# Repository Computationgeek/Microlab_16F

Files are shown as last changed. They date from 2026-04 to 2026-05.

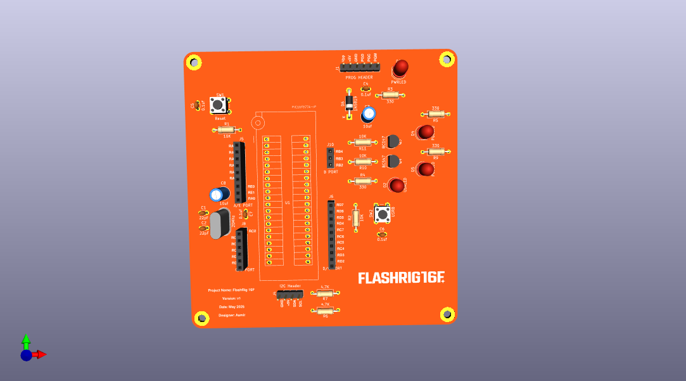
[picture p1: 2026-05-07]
FLASHRIG16F/images/ML16FPCB.png

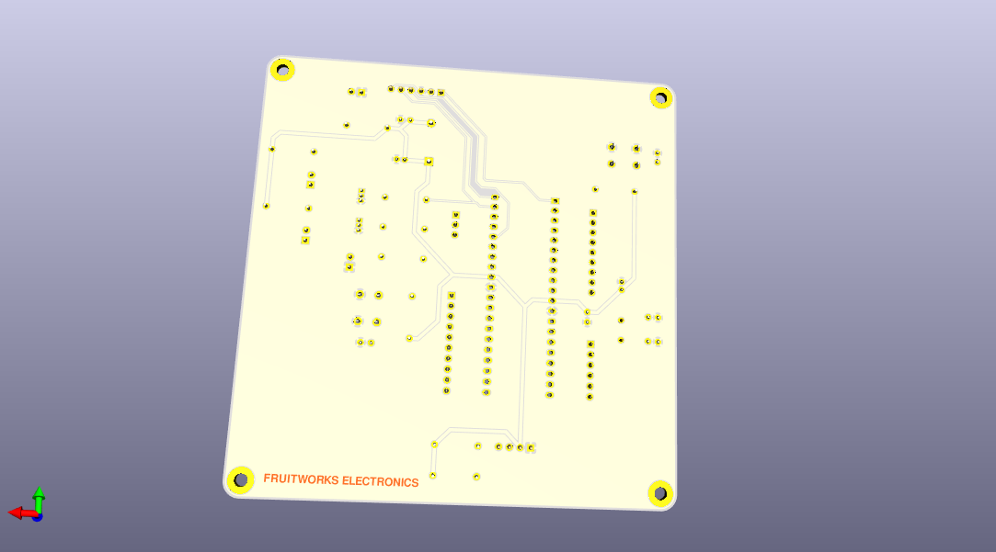
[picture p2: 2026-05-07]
FLASHRIG16F/images/ML16FPCBbcy.png

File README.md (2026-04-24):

# MicroLab 16F - PIC16F877A Development Board  
A hand-soldered PIC16F877A development board built entirely on perfboard. This project was born from a desire to gain a deep understanding of embedded systems hardware by building everything from scratch - no pre-made modules, no shortcuts.

hkio

## Vision & Motivation

In 2026, most developers rely on modern MCUs like ESP32 and STM32. But there's something special about PIC microcontrollers - they force you to understand registers, bit manipulation, and hardware at a fundamental level: no HAL abstraction, no hand-holding.

I built MicroLab 16F because:
- **Learning by doing** - Soldering each connection taught me more than any tutorial
- **Legacy matters** - PIC16F877A is still widely used in education and industry
- **Maker ethos** - If you can't build it yourself, you don't truly understand it
- **Fun over perfection** - This isn't a product, it's a learning journey

## Features

### Hardware
- **PIC16F877A** microcontroller (40-pin DIP)
- **20MHz HS crystal** oscillator with 22pF load capacitors
- **Mini breadboard** integrated prototyping area
- **10kΩ potentiometer** connected to RA0 (ADC input)
- **Active buzzer** driven by BC547 NPN transistor on RD1
- **User-addressable LED** on RB0
- **Two tactile buttons** - User button (configurable) and Reset button (MCLR)
- **USB-C power input** with 5V regulation
- **PICkit3 programming header** (ICSP interface)
- **Labeled pin headers** for all GPIO ports (PORTA, PORTB, PORTC, PORTD, PORTE)

### Power System
- USB-C input with 5V output
- Dedicated power LED indicator
- Decoupling capacitors for stable operation
- External power compatible (PICkit3 or USB-C)

## Detailed Specifications

PIC16F877A_Pinout_600x600

| Parameter | Value |
|---|---|
| **Microcontroller** | PIC16F877A (Microchip) |
| **Architecture** | 8-bit RISC |
| **Program Memory** | 14.3 KB (8192 words) Flash |
| **RAM** | 368 bytes |
| **EEPROM** | 256 bytes |
| **Clock Frequency** | 20 MHz (HS Crystal) |
| **I/O Pins** | 33 |
| **ADC Channels** | 8 (10-bit resolution) |
| **Timers** | 3 (Timer0/1/2) |
| **PWM Channels** | 2 (CCP modules) |
| **Serial Interfaces** | USART, I²C, SPI |
| **Operating Voltage** | 5V DC |
| **Power Source** | USB-C (5V) |
| **Programming Interface** | ICSP (In-Circuit Serial Programming) |
| **Programmer** | PICkit3

## Components Used

### Main Components
| Component | Specification | Quantity | Purpose |
|---|---|---|---|
| PIC16F877A-I/P | 40-pin DIP | 1 | Main microcontroller |
| Crystal Oscillator | 20 MHz HC-49S | 1 | Clock source |
| Ceramic Capacitor | 22pF | 2 | Crystal load capacitors |
| Ceramic Capacitor | 100nF | 5+ | Decoupling/bypass |
| Electrolytic Capacitor | 10µF 16V | 2 | Power filtering |
| BC547 NPN Transistor | TO-92 | 1 | Buzzer driver |
| Active Buzzer | 5V | 1 | Audio output |
| LED (5mm) | Red/Green | 3 | Power, User, Status indicators |
| Resistor | 10kΩ | 5+ | Pull-ups, current limiting |
| Resistor | 330Ω | 3 | LED current limiting |
| Resistor | 1kΩ | 1 | Base resistor for BC547 |
| Potentiometer | 10kΩ linear | 1 | Analog input (RA0) |
| Tactile Switch | 6×6mm | 2 | User button, Reset button |
| Mini Breadboard | 170 points | 1 | Prototyping area |
| USB-C Connector | Breakout module | 1 | Power input |
| Pin Headers | 2.54mm pitch | Multiple | GPIO breakout |
| Perfboard | Single-sided | 1 | PCB substrate |
| IC Socket | 40-pin DIP | 1 | PIC mounting (optional) |

## Software & Tools

### Development Environment
- **IDE:** MPLAB X IDE v6.20 (Last version with PICkit3 support)
- **Compiler:** MPLAB XC8 v2.46 (Free edition)
- **Programmer:** PICkit3 In-Circuit Debugger/Programmer
- **OS:** Tested on Linux Mint 21.3 & Windows 10/11

### Programming Setup
```bash
# Linux users: Add udev rules for PICkit3
sudo nano /etc/udev/rules.d/26-microchip.rules

# Add this line:
SUBSYSTEM=="usb", ATTR{idVendor}=="04d8", ATTR{idProduct}=="900a", MODE="0666", GROUP="plugdev"

# Reload rules
sudo udevadm control --reload-rules
sudo udevadm trigger
```

### Configuration Bits (Standard Setup)
```c
#pragma config FOSC = HS        // High-Speed crystal oscillator
#pragma config WDTE = OFF       // Watchdog Timer disabled
#pragma config PWRTE = ON       // Power-up Timer enabled
#pragma config BOREN = ON       // Brown-out Reset enabled
#pragma config LVP = OFF        // Low-Voltage Programming disabled (CRITICAL for ICSP)
#pragma config CPD = OFF        // Data EEPROM Code Protection off
#pragma config WRT = OFF        // Flash Program Memory Write Enable off
#pragma config CP = OFF         // Flash Program Memory Code Protection off
```

## Getting Started

### 1. Power Up
Connect the USB-C cable to a 5V power source (laptop, power bank, or wall adapter).
The power LED should illuminate.

### 2. Connect Programmer
**PICkit3 Pinout (6-pin header):**
1 - MCLR  → PIC Pin 1 (MCLR/VPP)
2 - VDD   → PIC Pin 11, 32 (VDD) - For sensing only
3 - GND   → PIC Pin 12, 31 (VSS)
4 - PGD   → PIC Pin 40 (RB7/PGD)
5 - PGC   → PIC Pin 39 (RB6/PGC)
6 - NC    → Not connected

## Troubleshooting

### PICkit3 "Target VDD too low" Error
**Problem:** VDD measured as 4.75V instead of 5.0V during programming.

**Cause:** Board peripherals (buzzer, LEDs) draw more current than PICkit3 can supply (~30-50mA limit).

**Solution:** 
1. In MPLAB X: Project Properties → PICkit3 → Power → UNCHECK "Power target from tool"
2. Power board via USB-C only
3. PICkit3 is used for programming signals, not power

### Programming Fails at Address 0x0000
**Cause:** Incorrect config bits or MCLR circuit issue.

**Solution:**
- Ensure `LVP = OFF` in config bits
- Verify 10kΩ pull-up resistor on MCLR pin
- Try a slower programming speed in MPLAB X settings

See [docs/troubleshooting.md](docs/troubleshooting.md) for more.

## Learning Resources

### PIC16F877A Deep Dive
- [Microchip Official Datasheet](https://www.microchip.com/wwwproducts/en/PIC16F877A)
- [Gooligum Electronics PIC Tutorials](https://www.gooligum.com.au/PIC-tutorials) - Best assembly/register-level guide
- Microchip Application Notes: AN526 (Math routines), AN617 (Fixed-point math)

### Recommended Reading
- "PIC Microcontroller Project Book" by John Iovine
- "Programming PIC Microcontrollers with XC8" by Armstrong Subero
- Embedded.fm podcast episodes on PIC architecture

## Why PIC16F877A in 2026?

**Yes, it's 25+ years old. Here's why it still matters:**

1. **Educational Gold Standard** - Used in universities worldwide to teach embedded fundamentals
2. **Register-Level Programming** - No bloated HALs hiding what's actually happening
3. **Industry Workhorse** - Still found in industrial equipment, automotive, and legacy systems
4. **Simplicity** - 35 instructions vs 100+ in ARM Cortex
5. **Availability** - Cheap, plentiful, easy to source
6. **Hands-On Learning** - DIP package = breadboard/perfboard friendly

Modern isn't always better. Sometimes you need to go back to basics.

## License

MIT License - Build, modify, share freely. Just give credit.

## 🔗 Links

- **Build Story:** [Hackster.io Project](https://www.hackster.io/aamirayaaz5/building-a-pic16f877a-development-board-from-scratch-in-2026-7d29bc)
- **LinkedIn Post:** [LinkedIn Post about the board](https://www.linkedin.com/posts/aamir-ayaaz-b5549a220_embeddedsystems-electronicsengineering-hardwaredesign-activity-7425852984116404224-cy4W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)

## Acknowledgments

Built with:
- Lots of solder fumes
- Multiple debugging sessions
- A stubborn refusal to give up when VDD dropped to 4.75V
- Coffee

**Special thanks to the PIC community and all the forum posts from 2005-2015 that saved this project.**

---

*"If you can't build it yourself, you don't truly understand it."*

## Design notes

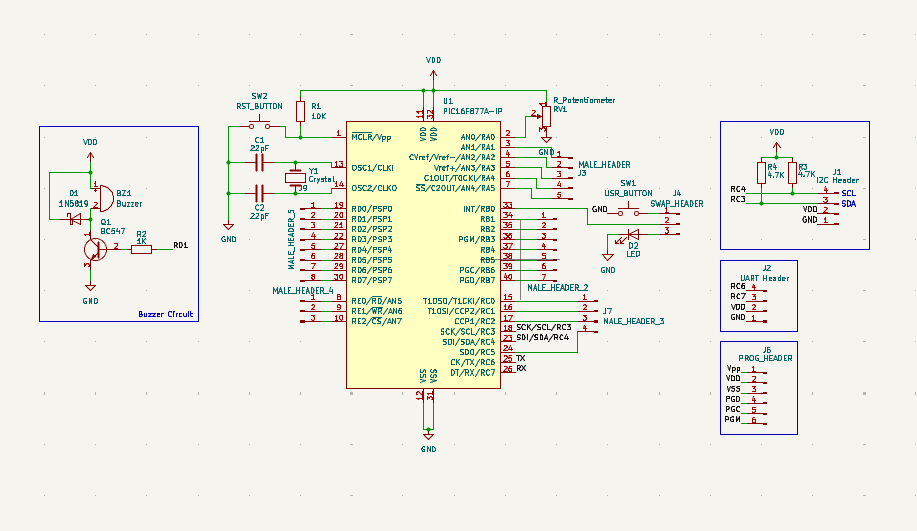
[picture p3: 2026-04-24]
Schematic/Schematic.png

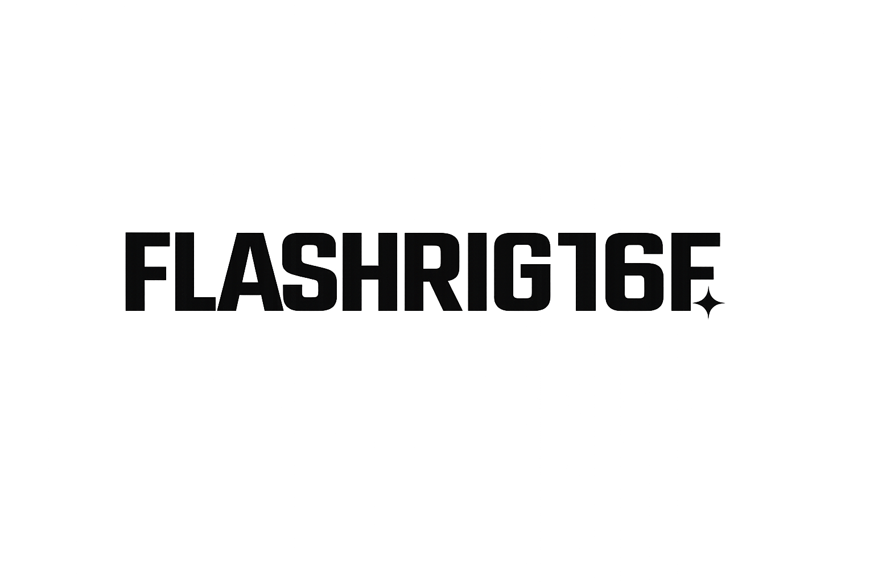
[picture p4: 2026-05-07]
FLASHRIG16F/images/3267ec91-bc9a-4d5c-b8c6-06fcff0d2900.png

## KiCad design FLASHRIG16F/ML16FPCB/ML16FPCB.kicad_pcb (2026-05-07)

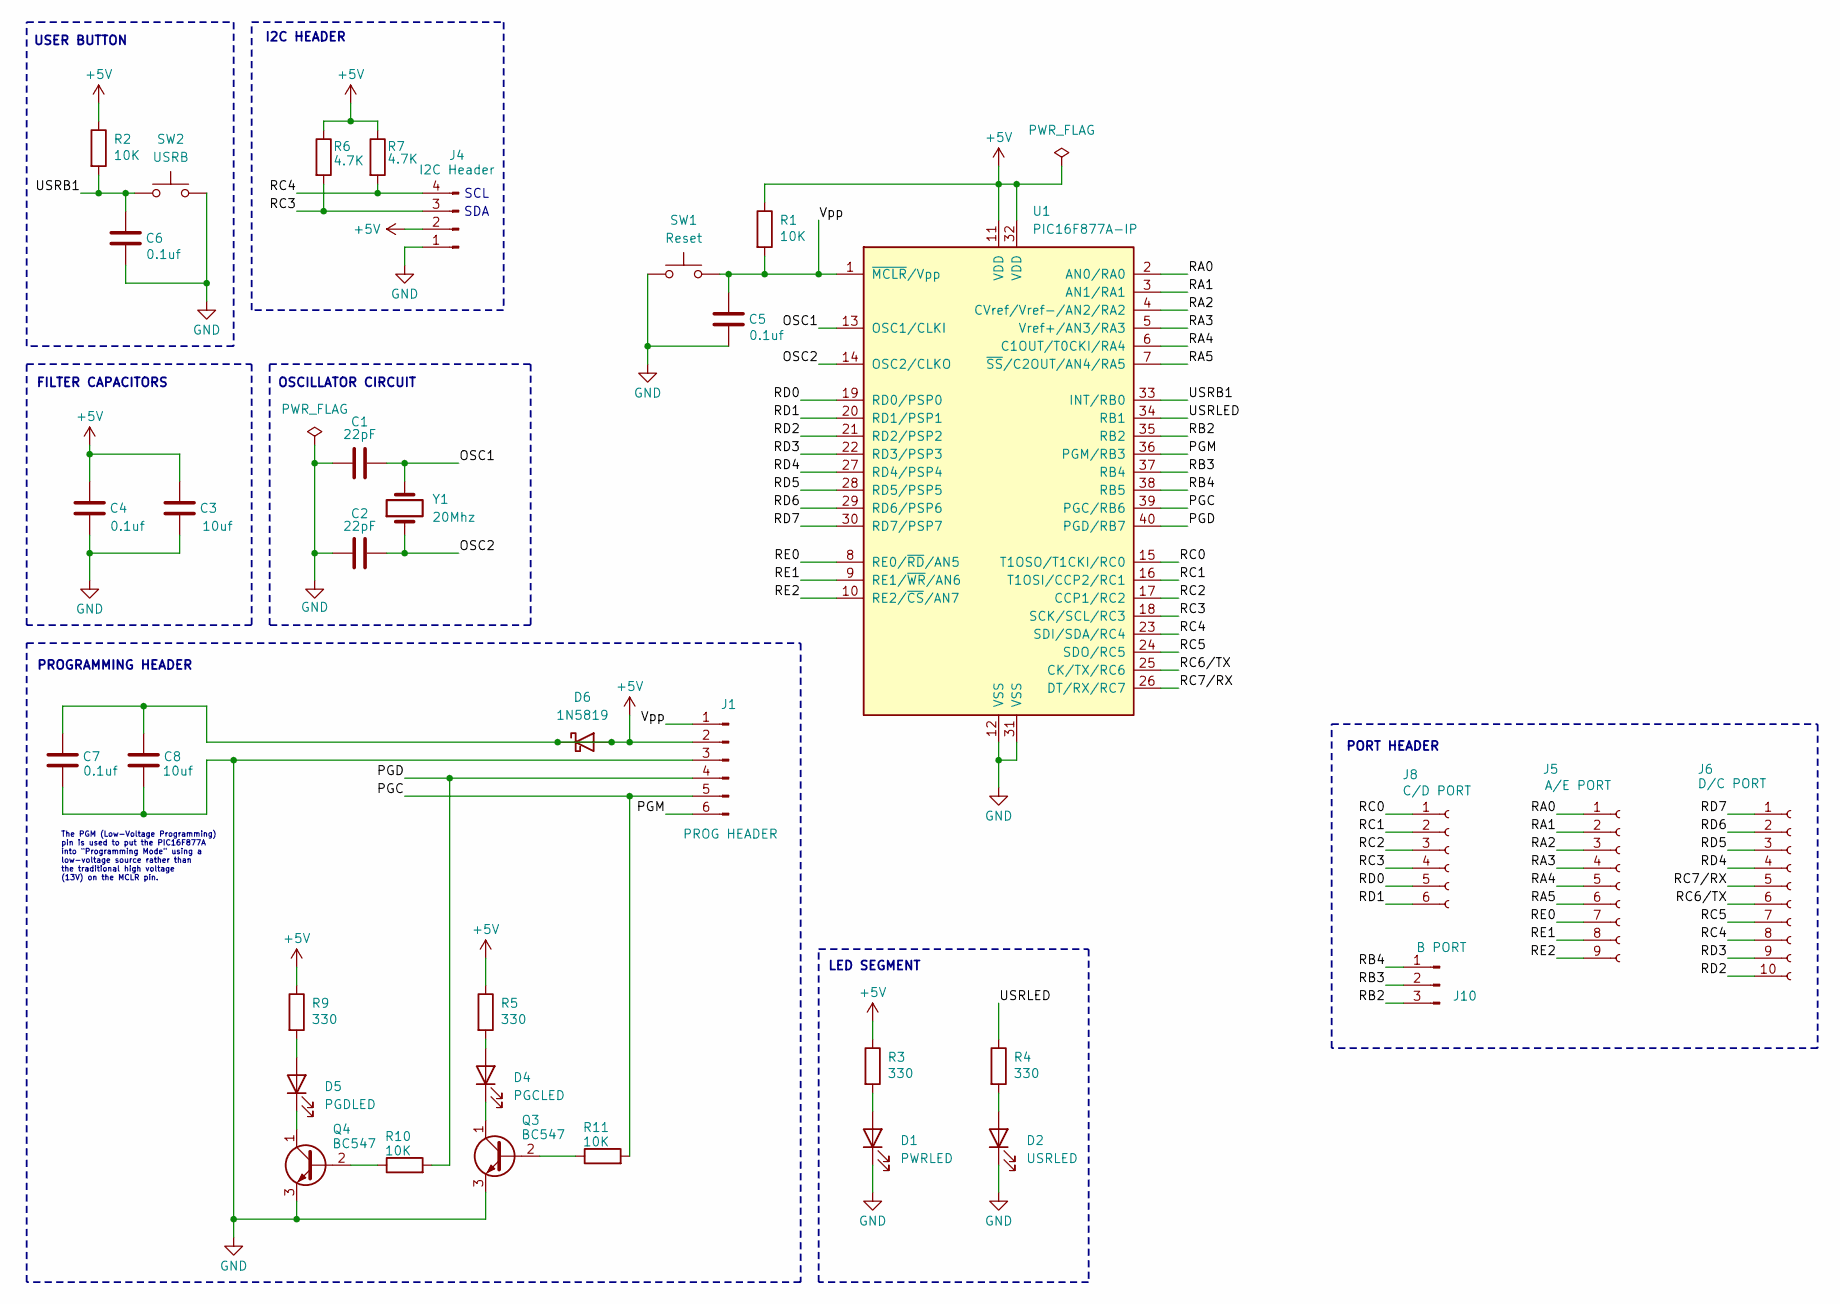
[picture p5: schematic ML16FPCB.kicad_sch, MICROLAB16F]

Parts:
C1, C2: 22pF; C_Disc_D3.0mm_W1.6mm_P2.50mm
C3, C8: 10uf; C_Radial_D5.0mm_H11.0mm_P2.00mm
C4, C5, C6, C7: 0.1uf; C_Disc_D3.0mm_W1.6mm_P2.50mm
D1: PWRLED; LED_D5.0mm
D2: USRLED; LED_D5.0mm
D4: PGCLED; LED_D5.0mm
D5: PGDLED; LED_D5.0mm
D6: 1N5819; D_DO-41_SOD81_P10.16mm_Horizontal
J1: PROG HEADER; PinHeader_1x06_P2.54mm_Vertical
J4: I2C Header; PinHeader_1x04_P2.54mm_Vertical
J5: A/E PORT; PinSocket_1x09_P2.54mm_Vertical
J6: D/C PORT; PinSocket_1x10_P2.54mm_Vertical
J8: C/D PORT; PinSocket_1x06_P2.54mm_Vertical
J10: B PORT; PinSocket_1x03_P2.54mm_Vertical
Q3, Q4: BC547; TO-92_Inline
R1, R2, R10, R11: 10K; R_Axial_DIN0207_L6.3mm_D2.5mm_P10.16mm_Horizontal
R3, R4, R5, R9: 330; R_Axial_DIN0207_L6.3mm_D2.5mm_P10.16mm_Horizontal
R6, R7: 4.7K; R_Axial_DIN0207_L6.3mm_D2.5mm_P10.16mm_Horizontal
SW1: Reset; SW_PUSH_6mm
SW2: USRB; SW_PUSH_6mm
U1: PIC16F877A-IP; 3M_Textool_240-1288-00-0602J_2x20_P2.54mm
Y1: 20Mhz; Crystal_HC49-U_Vertical

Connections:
+5V: C3.1, C4.1, C7.1, C8.1, D6.1 (K), D6.2 (A), J1.2, J4.2, R1.1, R2.1, R3.1, R5.1, R6.1, R7.1, R9.1, U1.11 (VDD), U1.32 (VDD)
/OSC1: C1.1, U1.13 (OSC1/CLKI), Y1.2
/OSC2: C2.2, U1.14 (OSC2/CLKO), Y1.1
/PGC: J1.5, R11.2, U1.39 (PGC/RB6)
/PGD: J1.4, R10.2, U1.40 (PGD/RB7)
/PGM: J1.6, U1.36 (PGM/RB3)
/RA0: J5.1, U1.2 (AN0/RA0)
/RA1: J5.2, U1.3 (AN1/RA1)
/RA2: J5.3, U1.4 (CVref/Vref-/AN2/RA2)
/RA3: J5.4, U1.5 (Vref+/AN3/RA3)
/RA4: J5.5, U1.6 (C1OUT/T0CKI/RA4)
/RA5: J5.6, U1.7 (~SS/C2OUT/AN4/RA5)
/RB2: J10.3, U1.35 (RB2)
/RB3: J10.2, U1.37 (RB4)
/RB4: J10.1, U1.38 (RB5)
/RC0: J8.1, U1.15 (T1OSO/T1CKI/RC0)
/RC1: J8.2, U1.16 (T1OSI/CCP2/RC1)
/RC2: J8.3, U1.17 (CCP1/RC2)
/RC3: J4.3, J8.4, R6.2, U1.18 (SCK/SCL/RC3)
/RC4: J4.4, J6.8, R7.2, U1.23 (SDI/SDA/RC4)
/RC5: J6.7, U1.24 (SDO/RC5)
/RC6/TX: J6.6, U1.25 (CK/TX/RC6)
/RC7/RX: J6.5, U1.26 (DT/RX/RC7)
/RD0: J8.5, U1.19 (RD0/PSP0)
/RD1: J8.6, U1.20 (RD1/PSP1)
/RD2: J6.10, U1.21 (RD2/PSP2)
/RD3: J6.9, U1.22 (RD3/PSP3)
/RD4: J6.4, U1.27 (RD4/PSP4)
/RD5: J6.3, U1.28 (RD5/PSP5)
/RD6: J6.2, U1.29 (RD6/PSP6)
/RD7: J6.1, U1.30 (RD7/PSP7)
/RE0: J5.7, U1.8 (RE0/~RD/AN5)
/RE1: J5.8, U1.9 (RE1/~WR/AN6)
/RE2: J5.9, U1.10 (RE2/~CS/AN7)
/USRB1: C6.1, R2.2, SW2.1, U1.33 (INT/RB0)
/USRLED: R4.1, U1.34 (RB1)
/Vpp: C5.1, J1.1, R1.2, SW1.2, U1.1 (~MCLR/Vpp)
GND: C1.2, C2.1, C3.2, C4.2, C5.2, C6.2, C7.2, C8.2, D1.1 (K), D2.1 (K), J1.3, J4.1, Q3.3 (E), Q4.3 (E), SW1.1, SW2.2, U1.12 (VSS), U1.31 (VSS)
unnamed: D1.2 (A), R3.2
unnamed: D2.2 (A), R4.2
unnamed: D4.2 (A), R5.2
unnamed: D4.1 (K), Q3.1 (C)
unnamed: D5.2 (A), R9.2
unnamed: D5.1 (K), Q4.1 (C)
unnamed: Q3.2 (B), R11.1
unnamed: Q4.2 (B), R10.1

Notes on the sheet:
I2C HEADER
OSCILLATOR CIRCUIT
FILTER CAPACITORS
LED SEGMENT
PROGRAMMING HEADER
SDA
The PGM (Low-Voltage Programming) pin is used to put the PIC16F877A into "Programming Mode" using a low-voltage source rather than the traditional high voltage (13V) on the MCLR pin.
USER BUTTON
PORT HEADER
SCL

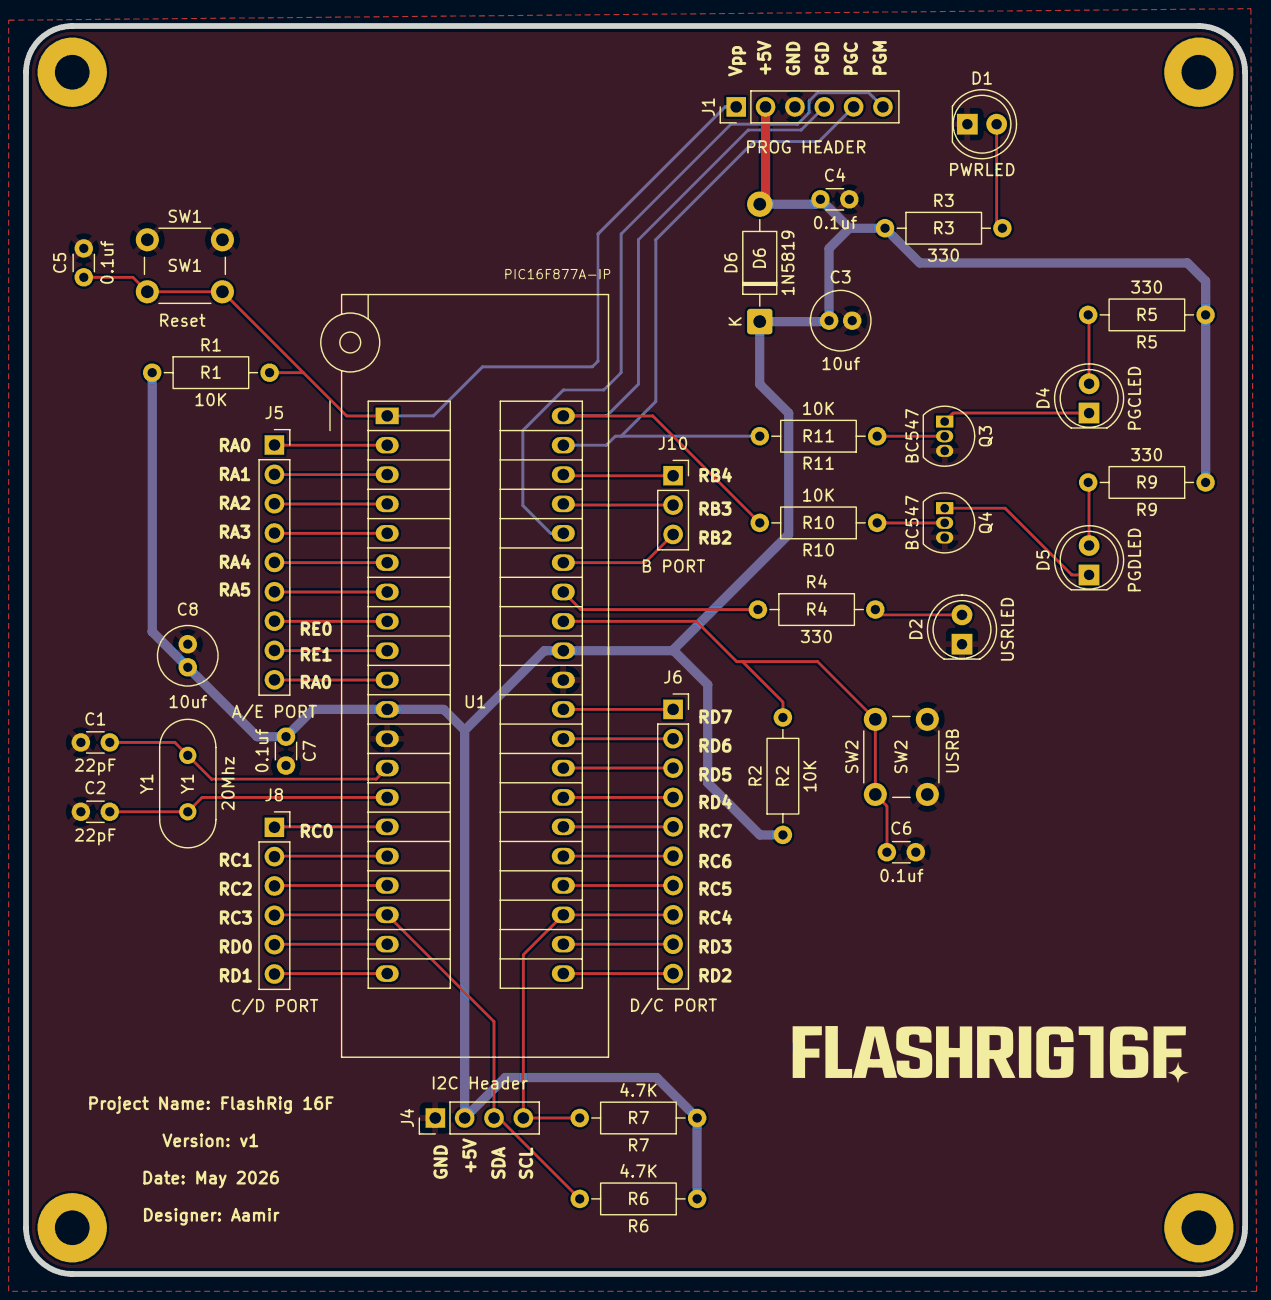
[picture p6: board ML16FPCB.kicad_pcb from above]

Board: 2 copper layers, 105.5 x 108.0 mm, 35 parts (0 on the bottom side), 46 nets.

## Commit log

2026-04-24 Create Schematic
2026-05-07 Uploading FlashRig PCb project
    [ML16FPCB.kicad_pcb, ML16FPCB.kicad_sch]
